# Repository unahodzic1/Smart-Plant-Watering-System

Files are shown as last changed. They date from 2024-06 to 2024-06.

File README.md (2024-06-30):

# Smart Plant Watering System
This system is designed to ensure your plants receive the right amount of water by automating the watering process based on soil moisture levels. Additionally, it provides a manual control option via the MQTTAnalyzer app on your mobile phone.

## Features
- Automated Watering: Automatically waters the plant when the soil moisture drops below a specific treshold, ensuring your plant is always well-hydrated.
- Manual Control: Allows users to manually control the watering process using the MQTTAnalyzer app.
- Continuous Monitoring: The soil moisture sensor constantly monitors the soil moisture level, providing real-time data to the system.

## Benefits
- Optimal Plant Care: Ensures your plants are watered accurately based on their needs.
- Remote Monitoring: Provides the ability to monitor and control your plant's watering needs from anywhere.
 
This project is perfect for plant enthusiasts and busy individuals who want to ensure their plants are healthy and well-maintained with minimal effort. Enjoy peace of mind knowing your plants are in good hands with our Smart Plant Watering System.

## YouTube video
https://youtu.be/v_NsG4rLjxo?feature=shared

## Team Members
1. [Benjamin Uzunović](https://github.com/BUzunovic1)
2. [Amina Čajić](https://github.com/aminacajic)
3. [Una Hodžić](https://github.com/unahodzic1)

----------------

*Faculty of Electrical Engineering*

*University of Sarajevo*

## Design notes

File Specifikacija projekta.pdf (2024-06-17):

Univerzitet u Sarajevu
Elektrotehnički fakultet

Ugradbeni sistemi 2023/24

### Specifikacija projekta

Smart Plant Watering System

Članovi tima:
Benjamin Uzunović,
Amina Čajić,
Una Hodžić

14.05.2024.

## 1 Specifikacija projekta

### 1.1 Tema projekta

Na našem projektu realizovali smo sistem za automatsko zalijevanje biljke kada nivo vlažnosti zemlje padne ispod određene vrijednosti. Također, korisnicima smo omogućili i upravljanje zalijevanjem biljke pomoću MQTTAnalyzer aplikacije na mobilnom telefonu.

### 1.2 Opis teme

Naš pametni sistem za zalijevanje kućnih biljaka radi na sljedeći način: koristeći senzor za vlažnost zemlje, sistem neprekidno mjeri nivo vlage u zemlji, te osigurava da se biljke zalijevaju tačno kada je to potrebno. Dakle, ukoliko je vlažnost zemlje ispod unaprijed određene vrijednosti od 50% maksimalne vlažnosti, aktivira se pumpa za vodu koja crpi vodu iz rezervoara (posude sa vodom), te je dostavlja u zemlju putem cijevi. Pumpom upravljamo pomoću releja. Nakon što se zalije biljka, pumpa se isključuje, te se ažuriraju podaci o vlažnosti zemlje na MQTTAnalyzer aplikaciji. Ovaj automatizirani proces navodnjavanja osigurava da biljke dobivaju potrebnu količinu vode, sprječavajući prekomjerno ili nedovoljno zalijevanje. Sistem omogućava i ručno upravljanje zalijevanjem pomoću MQTTAnalyzer aplikacije na mobilnom telefonu.

U rezervoaru se nalazi senzor za detekciju nivoa vode, te se taj nivo vode korisniku prikazuje na bar grafu, pri čemu svaka svjetleća crtica predstavlja 10% napunjenosti rezervoara (npr. ako su aktivne tri crtice, nivo vode iznosi 30% od maksimalnog kapaciteta). Ukoliko nivo vode postane nedovoljan za zalijevanje biljke, prikazuje se upozorenje na TFT displeju da zbog niskog nivoa vode u rezervoaru nije moguće zaliti biljku.

Također koristimo i senzor za mjerenje temperature i vlage zraka DHT11, kako bismo obavijestili korisnika o pogodnosti/nepogodnosti trenutnog položaja biljke (npr. ukoliko je biljka izložena previsokoj temperaturi, korisniku se ispisuje upozorenje na TFT displeju da je biljku potrebno premjestiti).

Projekat je realizovan koristeći dva razvojna sistema koji međusobno komuniciraju MQTT protokolom. Jedan razvojni sistem čita podatke sa senzora DHT11 i senzora za vlažnost zemlje, te očitane informacije šalje drugom razvojnom sistemu. Ovaj razvojni sistem također omogućava prikaz informacija o biljci korisniku na TFT displeju uz pomoć SPI komunikacije, te na MQTTAnalzyer aplikaciji uz pomoć MQTT protokola. Drugi razvojni sistem upravlja pumpom za vodu i mjeri nivo vode u rezervoaru, šaljući poruku prvom razvojnom sistemu u slučaju niskog nivoa vode. Na ovaj način smo, prema praktičnosti, rasporedili funkcionalnosti između dva razvojna sistema.

1

### 1.3 Komponente sistema

Koristili smo dva razvojna sistema picoETF, te smo kod implementirali u Thonny okruženju.

Resurs | Namjena
Senzor vlažnosti tla | Analogni ulaz
Senzor za mjerenje temperature i vlažnosti zraka DHT11 | Analogni ulaz
Senzor za mjerenje nivoa vode | Analogni ulaz
Relej | Digitalni izlaz
LED | Digitalni izlaz
Banggood displej | TFT LCD displej

2

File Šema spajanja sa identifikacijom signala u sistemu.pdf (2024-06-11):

Univerzitet u Sarajevu
Elektrotehnički fakultet

Ugradbeni sistemi 2023/24

### Šema spajanja sa identifikacijom signala u sistemu

Članovi tima:
Benjamin Uzunović,
Amina Čajić,
Una Hodžić

02.06.2024.

## Sadržaj

1 Šema - dijagram realiziran korištenjem alata Fritzing | 2
2 Blok-dijagram sistema | 3
3 Tabelarni prikaz ulaza i izlaza sistema | 4

## 1 Šema - dijagram realiziran korištenjem alata Fritzing

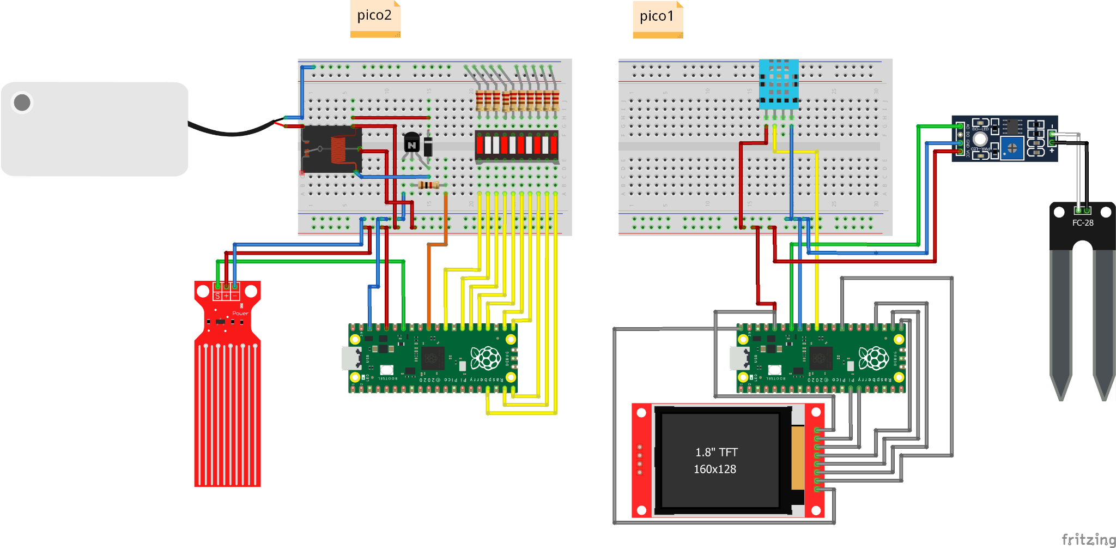
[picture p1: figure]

Slika 1: Šema spajanja komponenti

## 2 Blok-dijagram sistema

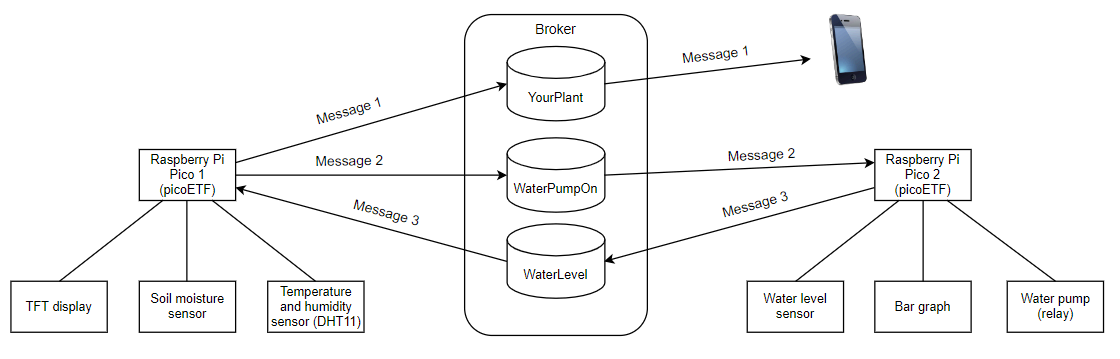
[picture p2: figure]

Slika 2: Blok-dijagram sistema

## 3 Tabelarni prikaz ulaza i izlaza sistema

U sljedećoj tabeli prikazani su ulazi i izlazi prvog korištenog razvojnog sistema picoETF.

Pin | Ulaz/izlaz | Opis
GP15 | Izlaz | Pinovi su korišteni za spajanje TFT displeja kako bi se na njemu ispisalo upozorenje ukoliko je spremnik sa vodom prazan ili je temperatura veća od 40 stepeni.

GP16

GP17

GP18

GP19

GP20

GP26

Ulaz (analogni)

Pinovi su korišteni za spajanje senzora DHT11 koji mjeri
VCC | | temperaturu i vlažnost zraka.

GND

GP28

| Ulaz (analogni) | Pinovi su korišteni za spajanje
| | senzora koji mjeri vlažnost
VCC | zemlje.

GND

U sljedećoj tabeli prikazani su ulazi i izlazi drugog korištenog razvojnog sistema picoETF.

Pin | Ulaz/izlaz | Opis

GP13

Izlaz (digitalni)

Pinovi su korišteni za spajanje
bar | grafa | koji | prikazuje
GP14 | količinu vode u posudi.

GP15

GP16

GP17

GP18

GP19

GP20

GP21

GP22

GP26 | Izlaz (digitalni) | Pin je korišten za spajanje releja koji upravlja pumpom za vodu.

GP28

Ulaz (analogni)

Pinovi su korišteni za spajanje senzora koji mjeri nivo vode u
VCC | posudi.

GND

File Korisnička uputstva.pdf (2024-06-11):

Univerzitet u Sarajevu
Elektrotehnički fakultet

Ugradbeni sistemi 2023/24

### Korisnička uputstva

Članovi tima:
Benjamin Uzunović,
Amina Čajić,
Una Hodžić

02.06.2024.

## Sadržaj

1 Korisnička uputsva | 2 (https://docs.google.com/document/d/1VI36eyJ1_fXaocYqqUzzcZVjm1f-AUL9/edit#heading=h.4gy0ug2lk0ci)

1

Pročitajte korisnička uputsva prije upotrebe sistema, u cilju izbjegavanja svake moguće opasnosti od nepravilne upotrebe!

Za korištenje pametnog sistema za zalijevanje biljaka, potrebno je imati dva razvojna sistema picoETF, kao i odgovarajuće komponente spojene na njih, prema prikazanoj šemi spajanja sa identifikacijom signala u sistemu. Razvojne sisteme picoETF potrebno je žičano povezati s računarima, na kojima je potrebno imati integrirano razvojno okruženje kao što je Thonny, koji možete preuzeti sa Thonny web stranice. (https://thonny-org.translate.goog/?_x_tr_sl=en&_x_tr_tl=hr&_x_tr_hl=hr&_x_tr_pto=wapp)

Otvorite Thonny okruženje na računarima, te spremite i pokrenite kod nazvan SLAVE.py na jedan picoETF, a MASTER.py na drugi. Kod se pokreće klikom na dugme Run, nakon čega sistem počinje sa radom. Prije spremanja koda, potrebno je zamijeniti WiFi postavke svojim podacima, na sljedeći način:
1. Otvorite kod (PICO1.py ili PICO2.py).
2. Pronađite liniju koda koja izgleda ovako: nic.connect('NazivVasegWiFi', 'SifraVasegWiFi').
3. Zamijenite 'NazivVasegWiFi' nazivom Vaše WiFi mreže.
4. Zamijenite 'SifraVasegWiFi' šifrom Vaše WiFi mreže.
5. Sačuvajte izmjene i pokrenite kod.

Umetnite senzor za mjerenje vlažnosti zemlje u saksiju s biljkom, pazeći da senzor ostane u zemlji sve dok je sistem priključen na napajanje. Zatim napunite rezervoar s vodom. Kada sistem bude pokrenut, automatski će zalijevati biljke kada nivo vlage u zemlji padne ispod određene vrijednosti. Sistem omogućava i ručno upravljanje zalijevanjem za koje je potrebno instalirati aplikaciju MQTTAnalyzer na svoj mobilni telefon, te se povezati na MQTT broker korištenjem sljedećih postavki:

Server: broker.hivemq.com,
User: (ostavite prazno),
Password: (ostavite prazno),
Port: 1883.

Nakon što se povežete, dodajte pretplatu na temu pico/YourPlant.
Da biste ručno zalili biljku, pošaljite poruku “Water the plant” na temu pico/YourPlant.
U okviru iste teme možete pratiti nivo vlage u zemlji koji se ispisuje svakih 20 sekundi.

Na bar grafu možete pratiti nivo vode u rezervoaru, pri čemu svaka svjetleća crtica predstavlja 10% napunjenosti rezervoara. Ako su aktivne tri crtice, nivo vode iznosi 30% od maksimalnog kapaciteta. Ukoliko nivo vode postane nedovoljan za zalijevanje biljke, ili ako je biljka izložena nepovoljnim temperaturnim uslovima, na TFT displeju će se prikazati odgovarajuća upozorenja.

2

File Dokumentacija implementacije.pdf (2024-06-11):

Univerzitet u Sarajevu
Elektrotehnički fakultet

Ugradbeni sistemi 2023/24

### Dokumentacija implementacije

Članovi tima:
Benjamin Uzunović,
Amina Čajić,
Una Hodžić

02.06.2024.

## Sadržaj

1 Dokumentacija implementacije | 2
1.1 Razvojni sistem picoETF1 | 2
1.2 Razvojni sistem picoETF2 | 2

1

## 1 Dokumentacija implementacije

Za implementaciju našeg pametnog sistema za zalijevanje biljaka koristili smo dva razvojna sistema picoETF koji međusobno komuniciraju putem MQTT protokola. Radi jednostavnosti i bolje čitljivosti dokumentacije, odvojeno ćemo opisivati funkcionalnosti razvojnih sistema koje ćemo zvati picoETF1 i picoETF2.

### 1.1 Razvojni sistem picoETF1

Na razvojni sistem picoETF1 je spojen senzor za mjerenje vlažnosti zemlje koji svakih 20 sekundi očitava vrijednost, te objavljuje poruku putem hivemq brokera na temu WaterPumpOn ukoliko je vlažnost zemlje ispod 50%, nakon čega će se zaliti biljka. Također, i korisnik može poslati istu MQTT poruku na temu YourPlant, čime smo omogućili i manuelno zalijevanje biljke.
Senzor za mjerenje vlažnosti zemlje sastoji se od dvije sonde. Sonde se koriste kako bi se omogućio prolazak struje kroz tlo, te kako bismo na osnovu otpora na kraju dobili vrijednost vlage. Kako bismo izračunali vrijednost vlage u postotcima, morali smo odrediti minimalnu i maksimalnu vrijednost koju senzor može očitati. U jako suhoj zemlji očitana je vrijednost približna 65535 a u jako vlažnoj zemlji očitana vrijednost je iznosila 1000.
Koristeći Banggood displej omogućili smo ispis određenih upozorenja:
- upozorenje da nije moguće zaliti biljku ukoliko nema vode u rezervoaru (ispisuje se kada picoETF2 pošalje MQTT poruku na temu WaterLevel koju picoETF1 prima jer je pretplaćen na nju)
- upozorenje da je položaj biljke nepovoljan (ispisuje se kada je temperatura izmjerena pomoću DHT11 senzora veća od 40 stepeni)
Također, razvojni sistem picoETF1 ispisuje vrijednost vlažnosti slanjem poruke na temu YourPlant, kako bi korisnik u svakom trenutku bio obaviješten o stanju u kojem se njegova biljka nalazi.

### 1.2 Razvojni sistem picoETF2

Na razvojni sistem picoETF2 spojen je senzor za mjerenje nivoa vode u posudi. Ovaj senzor ima deset izloženih bakrenih traka čija kombinacija djeluje poput promjenjivog otpornika, mijenjajući vrijednost otpora u zavisnosti od nivoa vode. Očitanu vrijednost dalje svodimo na opseg od 0 do 10 kako bismo nivo vode ispisali na bar grafu koji se sastoji od 10 segmenata (ukoliko je posuda 30% ispunjena vodom, upaljena su 3 segmenata bar grafa itd.)
Razvojni sistem picoETF2 je pretplaćen na teme WaterPumpOn i YourPlant, te nakon primanja poruke uključuje relej koji upravlja pumpom za vodu. Relej je uključen 2 sekunde, te je to vrijeme rada pumpe prilikom jednog zalijevanja.

2

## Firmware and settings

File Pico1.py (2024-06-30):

from machine import Pin, ADC, SPI
from ili934xnew import ILI9341, color565
from micropython import const
from umqtt.robust import MQTTClient
from dht import DHT11
import network
import time
import ujson
import os
import glcdfont
import tt14
import tt24
import tt32

# Sensors

soil_moisture_sensor = ADC(Pin(28))
dht11_sensor = DHT11(Pin(26))

# TFT display

SCR_WIDTH = const(320)
SCR_HEIGHT = const(240)
SCR_ROT = const(2)
CENTER_Y = int(SCR_WIDTH / 2)
CENTER_X = int(SCR_HEIGHT / 2)

TFT_CLK_PIN = const(18)
TFT_MOSI_PIN = const(19)
TFT_MISO_PIN = const(16)
TFT_CS_PIN = const(17)
TFT_RST_PIN = const(20)
TFT_DC_PIN = const(15)

fonts = [glcdfont, tt14, tt24, tt32]

spi = SPI(
    0,
    baudrate=62500000,
    miso=Pin(TFT_MISO_PIN),
    mosi=Pin(TFT_MOSI_PIN),
    sck=Pin(TFT_CLK_PIN))

display = ILI9341(
    spi,
    cs=Pin(TFT_CS_PIN),
    dc=Pin(TFT_DC_PIN),
    rst=Pin(TFT_RST_PIN),
    w=SCR_WIDTH,
    h=SCR_HEIGHT,
    r=SCR_ROT)

# Displaying warning messages 

def print_high_temp_warning_message_TFT():
    display.set_pos(50, 50)
    display.rotation = 2
    display.set_font(tt14)
    display.set_color(color565(255, 255, 255), color565(0, 0, 0))
    display.print("High temperature! Move your plant!")

def print_low_water_lvl_warning_message_TFT():
    display.set_pos(50, 90)
    display.rotation = 2
    display.set_font(tt14)
    display.set_color(color565(255, 255, 255), color565(0, 0, 0))
    display.print("Low water level! Can't water the plant.")

# Connecting to the WiFi

nic = network.WLAN(network.STA_IF)
nic.active(True)
nic.connect('Lab220', 'lab220lozinka')

while not nic.isconnected():
    print("Waiting for connection...")
    time.sleep(1)

print("WLAN connection established.")
ipaddr = nic.ifconfig()[0]

print("Network settings:")
print(nic.ifconfig())

display_message_until = 0

# Sub procedure executed upon receiving MQTT messages

def sub(topic, msg):
    global display_message_until
    if topic == b'pico/WaterLevel':
        if msg == b'0':
            print_low_water_lvl_warning_message_TFT()
            display_message_until = time.time() + 3
        elif msg == b'1':
            display.erase()
            temperature_humidity()

# Establishing connection with MQTT broker

mqtt_conn = MQTTClient(client_id='Pico1', server='broker.hivemq.com', user='', password='', port=1883)
mqtt_conn.set_callback(sub)
mqtt_conn.connect()
mqtt_conn.subscribe(b"pico/WaterLevel") 

def low_soil_moisture():
    try:
        soil_moisture = soil_moisture_sensor.read_u16()
        if soil_moisture > 32000 and soil_moisture < 65000:
            mqtt_conn.publish(b'pico/WaterPumpOn', b'1')
            print("Message sent: Water pump is on.")
    except OSError as e:
        print("Error: ", e)

def print_soil_moisture():
    try:
        soil_moisture = soil_moisture_sensor.read_u16()
        max_moisture = 65535
        min_moisture = 1000
        moisture = (max_moisture - soil_moisture_sensor.read_u16()) * 100 / (max_moisture - min_moisture)
        msg = b'{\n "Soil moisture":' + str(round(moisture)).encode() + b'%\n}'
        mqtt_conn.publish(b'pico/YourPlant', msg)
    except OSError as e:
        print("Error: ", e)

def temperature_humidity():
    try:
        dht11_sensor.measure()
        temperature = dht11_sensor.temperature()
        humidity = dht11_sensor.humidity()
        if temperature > 40:
            print_high_temp_warning_message_TFT()
        else:
            display.erase()

    except OSError as e:
        print("Error:", e)

temp_humidity_interval = 60
soil_moisture_interval = 20
mqtt_check_interval = 1

last_temp_humidity_check = 0
last_soil_moisture_check = 0
last_mqtt_check = 0

while True:
    current_time = time.time()
    
    if current_time - last_mqtt_check >= mqtt_check_interval:
        mqtt_conn.check_msg()
        last_mqtt_check = current_time

    if current_time - last_temp_humidity_check >= temp_humidity_interval:
        temperature_humidity()
        last_temp_humidity_check = current_time

    if current_time - last_soil_moisture_check >= soil_moisture_interval:
        low_soil_moisture()
        print_soil_moisture()
        last_soil_moisture_check = current_time
    
    if display_message_until and current_time >= display_message_until:
        display.erase()
        display_message_until = 0
    
    time.sleep(0.1)

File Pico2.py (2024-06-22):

from machine import Pin, ADC, Timer
import network
import time
from umqtt.robust import MQTTClient

# Water level 

water_level_sensor = ADC(Pin(28))

# Maximum value that the water level sensor can read

max_value = 65535

# Relay that controls the pump

water_pump = Pin(26, Pin.OUT)

# Bar graph

pin = [22, 21, 20, 19, 18, 17, 16, 15, 14, 13]
led = []
for i in range(10):
    led.append(Pin(pin[i], Pin.OUT))

# Connecting to the WiFi

nic = network.WLAN(network.STA_IF)
nic.active(True)
nic.connect('Lab220', 'lab220lozinka')

while not nic.isconnected():
    print("Waiting for connection ...")
    time.sleep(1)

print("WLAN connection established")
ipaddr = nic.ifconfig()[0]

print("Network settings:")
print(nic.ifconfig())

# Sub procedure executed upon receiving MQTT messages

def sub(topic, msg):
    print('Topic:', topic)
    print('Message:', msg)
    if topic == b'pico/WaterPumpOn':
        if msg == b'1':
            water_pump.value(1)
            print("Water pump on.")
            time.sleep(2)
            water_pump.value(0)
        else:
            water_pump.value(0)
    if topic == b'pico/YourPlant':
        if msg == b'Water the plant':
            water_pump.value(1)
            print("Water pump on.")
            time.sleep(2)
            water_pump.value(0)
        else:
            water_pump.value(0)

# Establishing connection with MQTT broker

mqtt_conn = MQTTClient(client_id='Pico2', server='broker.hivemq.com', user='', password='', port=1883)
mqtt_conn.set_callback(sub)
mqtt_conn.connect()
mqtt_conn.subscribe(b"pico/WaterPumpOn")  
mqtt_conn.subscribe(b"pico/YourPlant")  

def water_level_bar_graph():
    value = water_level_sensor.read_u16()
    num_leds = int((value / max_value) * 10)
    for i in range(10):
        led[i].value(1 if i < num_leds else 0)

def low_water_level():
    water_level = water_level_sensor.read_u16()
    if water_level < 6500:
        mqtt_conn.publish(b'pico/WaterLevel', b'0')
        print("Low water level.")
    if water_level > 6500:
        mqtt_conn.publish(b'pico/WaterLevel', b'1')

while True:
    mqtt_conn.check_msg()
    water_level_bar_graph()
    low_water_level()
    value = water_level_sensor.read_u16()
    print(value)
    time.sleep(1)
